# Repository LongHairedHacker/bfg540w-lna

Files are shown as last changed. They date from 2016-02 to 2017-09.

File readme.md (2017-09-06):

BFG 540W LNA
============
A low noise amplifier for NOAA satellite APT signals.

Original design by **YU1AW**
Refer to his [documentation](http://www.qsl.net/yu1aw/LNA/bfp196peng.htm)
for additional information and tips for tuning.

See [plot/lna.pdf](plot/lna.pdf) for the schematic and [parts.md](parts.md) for the BOM.

PCB
---
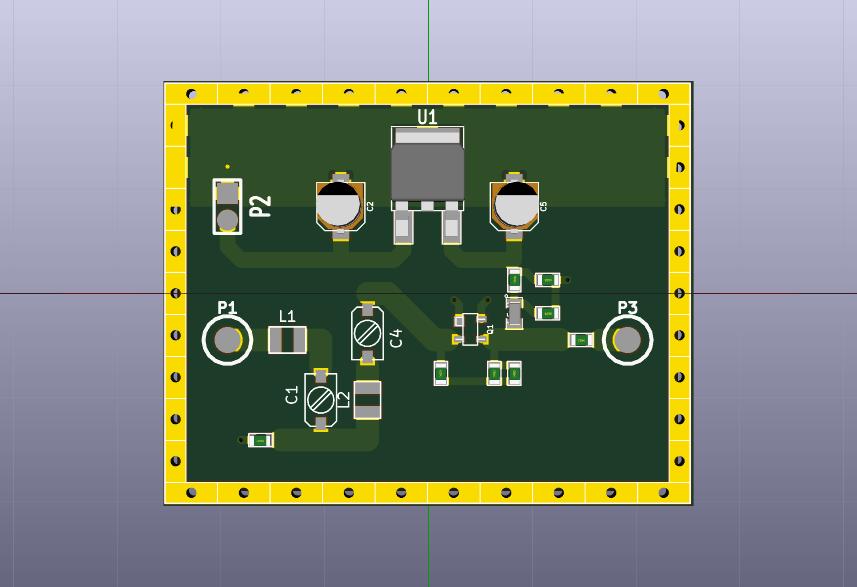
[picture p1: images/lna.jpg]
PCB rendering


Results
--------
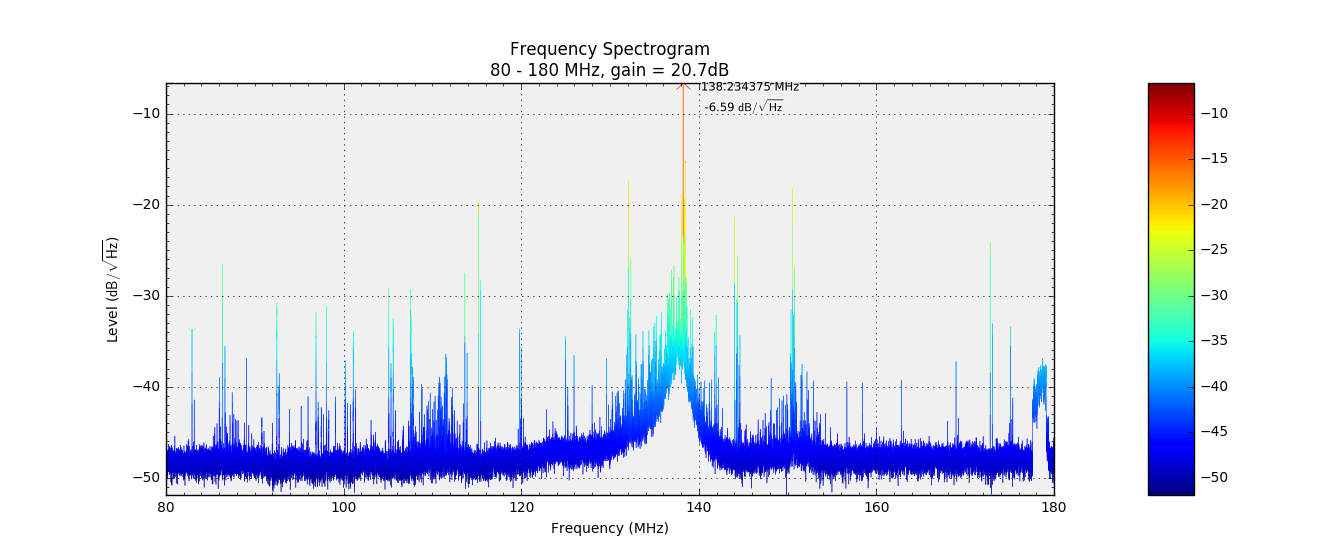
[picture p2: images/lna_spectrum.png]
spektrum


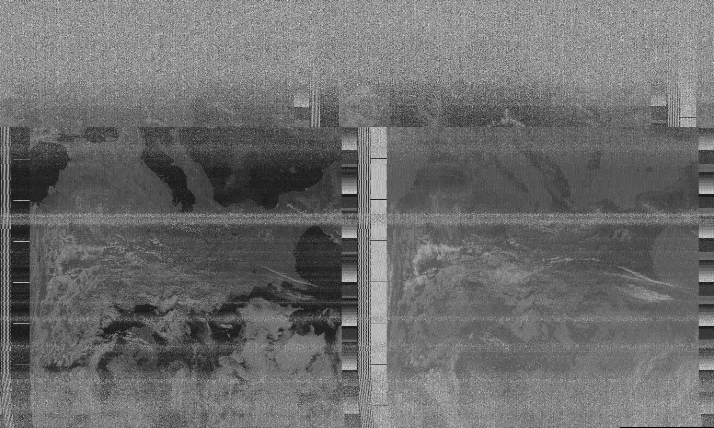
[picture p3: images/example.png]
apt sample


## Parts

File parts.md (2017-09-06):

Of the shelf
============

| Part				| Manufacturer Part	|
|---|---|
| 10V Regulator		| UA7810CKTTR		|
| BFG 540W			| BFG 540W			|
| Trimmer 10pf		| TZC3R100A110R00 	|
| Inductor 0.4040uH	| PE-1008CM401KTT 	|
| Inductor 1.5uH 	|  CV201210-1R5K |
| 6.8pF 0603	 | 251R14S6R8CV4T	|
| 33pF 0603 | C0603C330J5GACTU  |
| 680pF 0603		| CL10B681KB8NNNC |
| 22nF 0603			| CL10B223KB8SFNC |
| 82 0603			| |
| 1k 0803			| |
| 47k 0603			| |
| 1uF				| UWJ1H010MCL1GB |

Selfwound coils
===============
Inductance: 404.3 nH
Length : 10mm
Diameter: 8mm
Windings: 8

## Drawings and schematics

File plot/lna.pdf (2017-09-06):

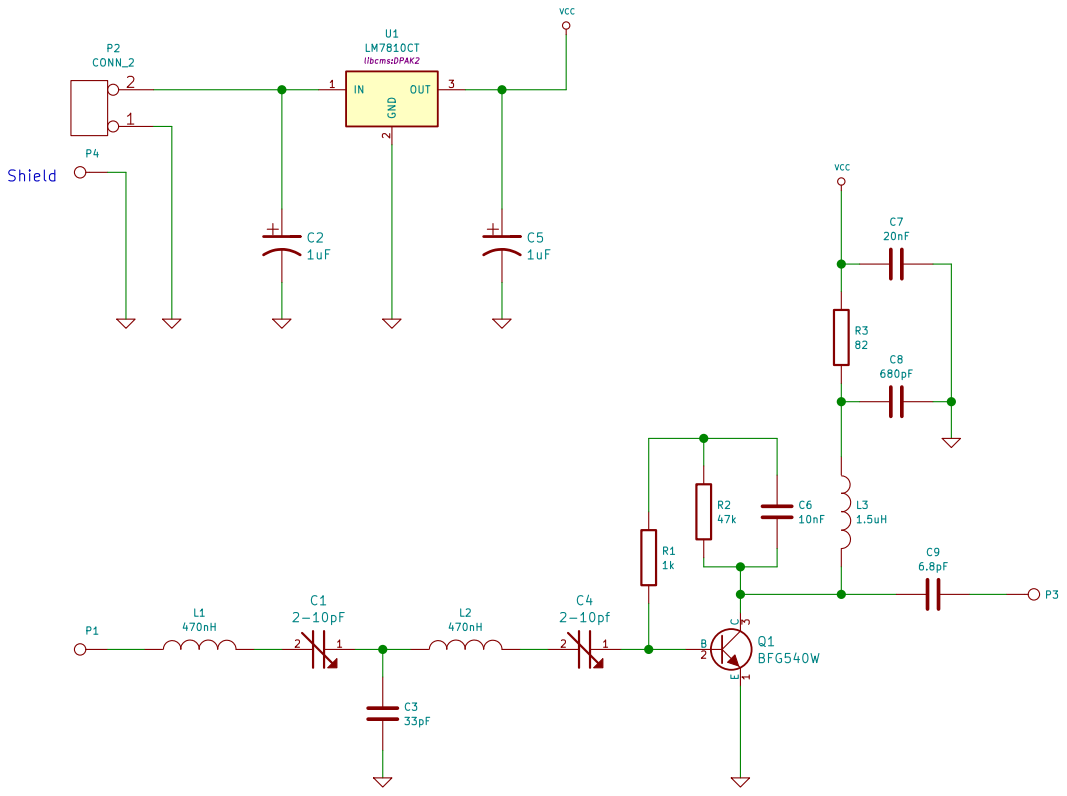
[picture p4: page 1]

Id: 1/1 Title: File: lna.sch Sheet: / P1

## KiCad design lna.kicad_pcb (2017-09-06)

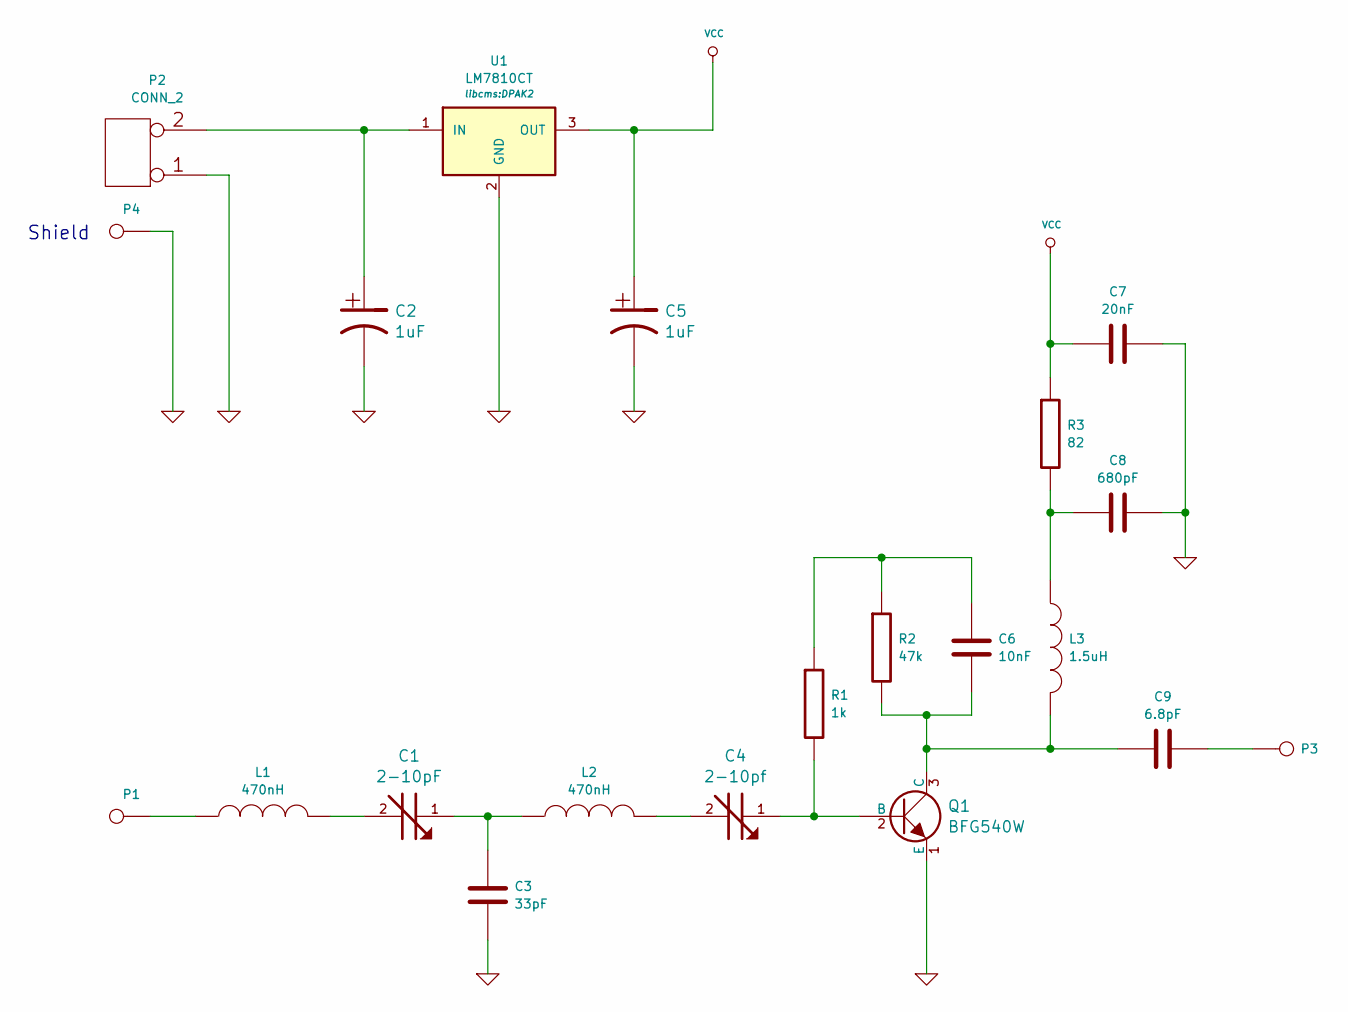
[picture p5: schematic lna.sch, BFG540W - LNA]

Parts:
C1: 2-10pF; TZC3
C2, C5: 1uF; c_elec_4x4.5
C3: 33pF; SM0603
C4: 2-10pf; TZC3
C6: 10nF; SM0603
C7: 20nF; SM0603
C8: 680pF; SM0603
C9: 6.8pF; SM0603
L1, L2: 470nH; SM1008
L3: 1.5uH; SM0805
P1, P3: CONN_1; 1pin
P2: CONN_2; SIL-2
P4: CONN_1; Shield
Q1: BFG540W; sot143B
R1: 1k; SM0603
R2: 47k; SM0603
R3: 82; SM0603
U1: LM7810CT; DPAK2

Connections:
GND: C2.2, C3.2, C5.2, C7.1, C8.1, P2.1, P4.1, Q1.1 (E), U1.2 (GND)
unnamed: C1.1, C3.1, L2.1
unnamed: C1.2, L1.2
unnamed: C2.1, P2.2 (PM), U1.1 (IN)
unnamed: C4.1, Q1.2 (B), R1.2
unnamed: C4.2, L2.2
unnamed: C6.1, R1.1, R2.1
unnamed: C6.2, C9.2, L3.2, Q1.3 (C), R2.2
unnamed: C8.2, L3.1, R3.2
unnamed: C9.1, P3.1
unnamed: L1.1, P1.1
VCC: C5.1, C7.2, R3.1, U1.3 (OUT)

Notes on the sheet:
Shield

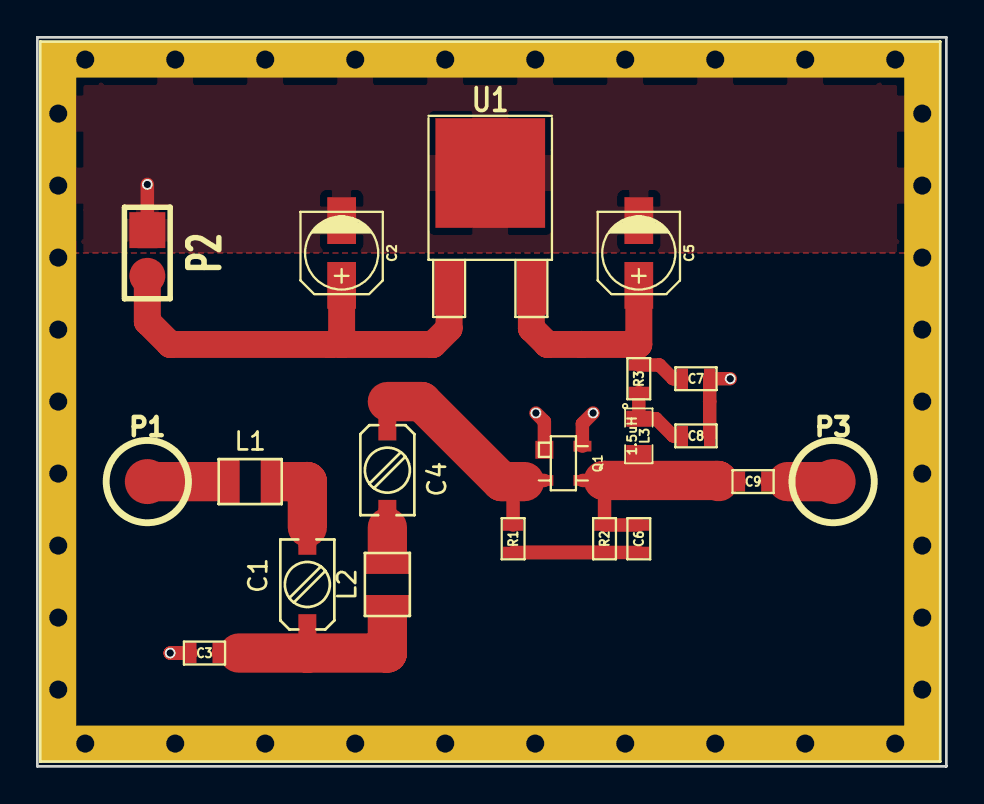
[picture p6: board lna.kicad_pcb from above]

Board: 2 copper layers, 50.5 x 40.5 mm, 21 parts (0 on the bottom side), 12 nets.

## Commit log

2016-02-01 First version
    [lna.kicad_pcb, lna.sch]
2016-02-01 Optimizes the layout
    [lna.kicad_pcb]
2016-02-01 Those are called LC filters not CL filters ... D'oh
    [lna.kicad_pcb, lna.sch]
2016-02-03 This might be 50Ohm
    [lna.kicad_pcb]
2017-09-06 Added docs and gebers
    [lna.kicad_pcb, lna.sch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]
